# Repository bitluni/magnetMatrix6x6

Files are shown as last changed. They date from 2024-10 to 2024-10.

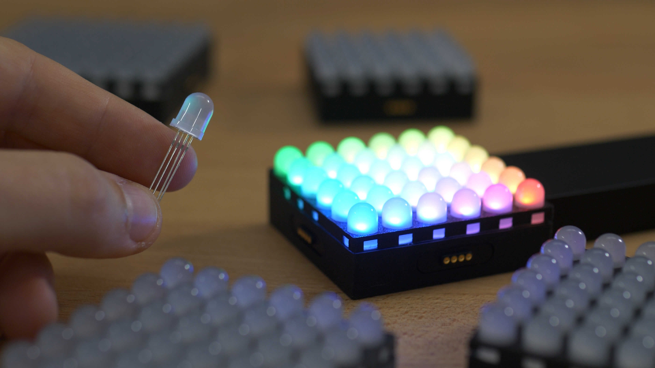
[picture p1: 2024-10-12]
cover.jpg

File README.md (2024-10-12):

# project video 
https://youtu.be/L2J_eNgjxio

# prerquisites 
Ardino IDE https://www.arduino.cc/en/software

ATTiny library https://github.com/SpenceKonde/megaTinyCore

UPDI progammer https://github.com/ElTangas/jtag2updi

# Parts (affiliate)
ATTiny1604

Magnet Connectors https://aliexpress.bitluni.net/magnetConnectors

WS2812D 5 & 8mm https://aliexpress.bitluni.net/ws2812d

# Support
https://paypal.me/bitluni

https://github.com/sponsors/bitluni

https://patreon.com/bitluni

have fun & thx for the support

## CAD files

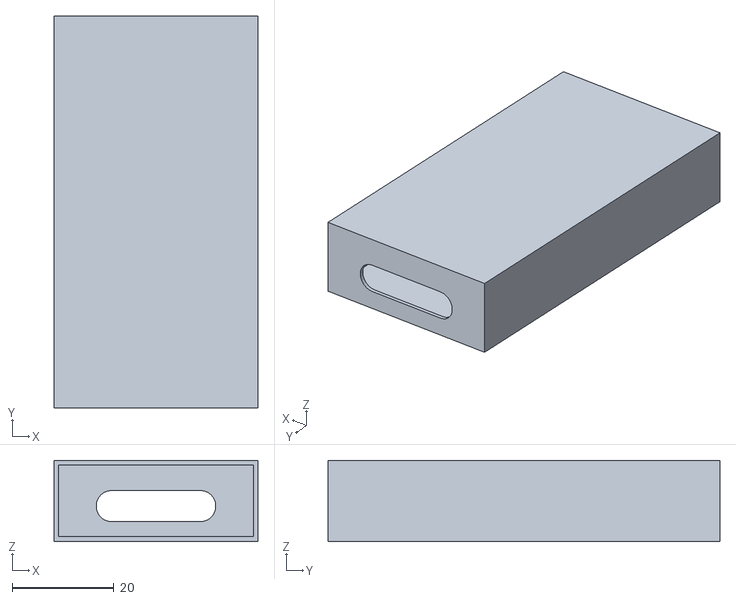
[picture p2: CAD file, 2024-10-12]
Models/battcase.stl
40.0 x 77.0 x 16.0

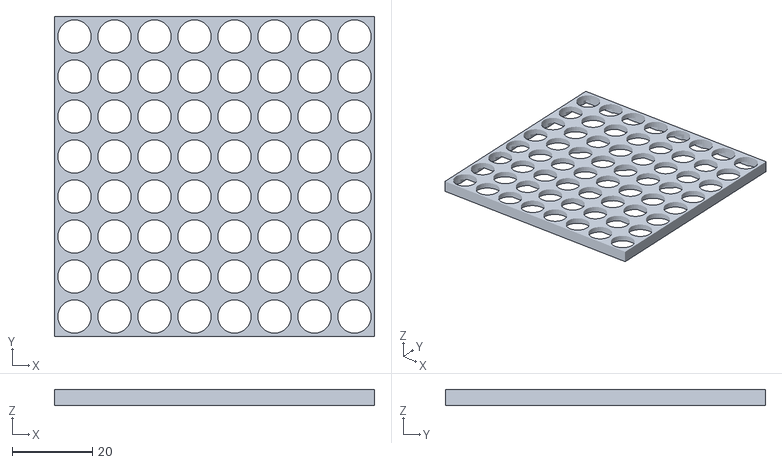
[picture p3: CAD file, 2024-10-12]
Models/top1.stl
80.0 x 80.0 x 4.00

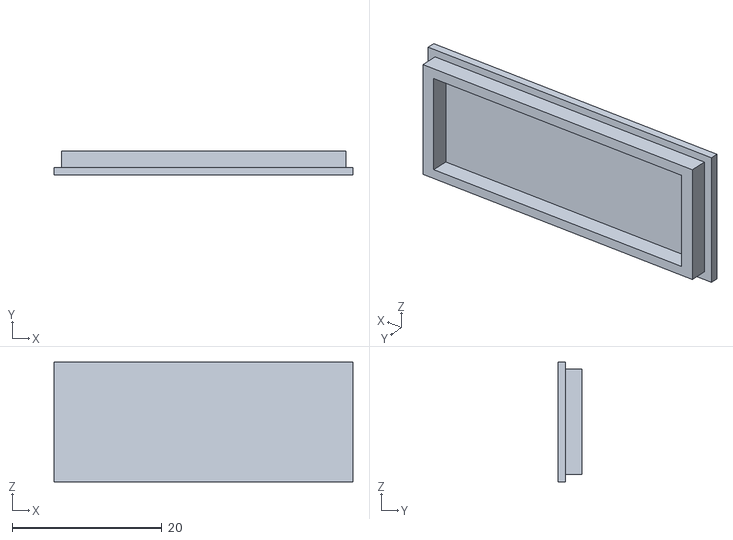
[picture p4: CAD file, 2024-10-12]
Models/battcap.stl
40.0 x 3.18 x 16.0

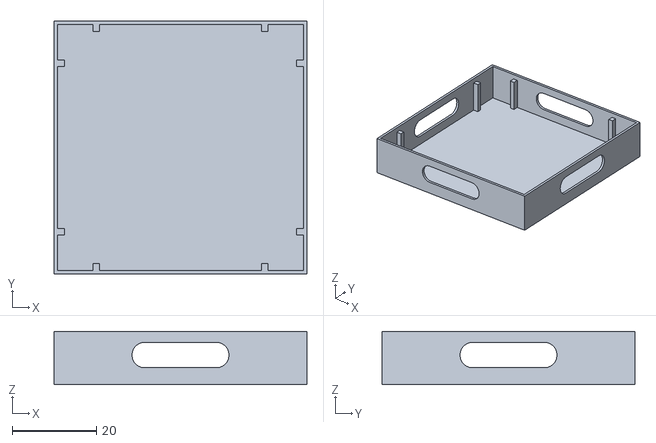
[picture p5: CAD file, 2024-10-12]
Models/bottom6x6.stl
60.0 x 60.0 x 12.6

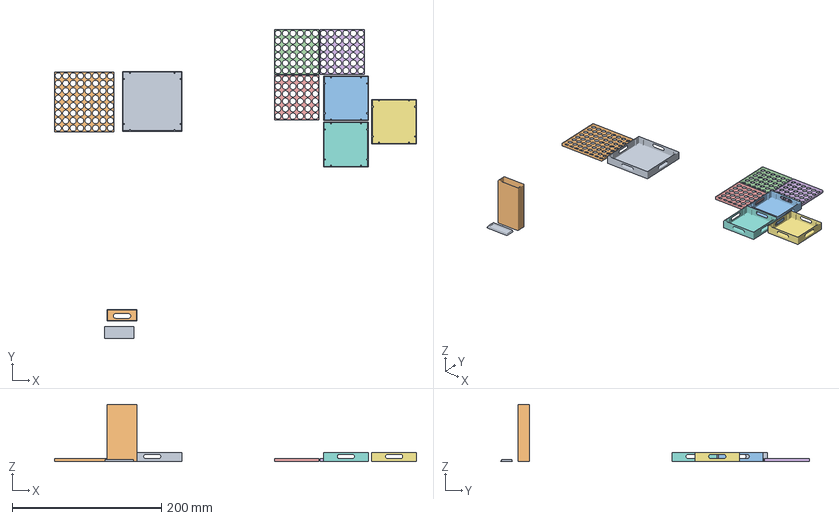
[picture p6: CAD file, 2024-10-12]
Models/parts.3mf
485.1 x 413.8 x 77.0 mm
bottom1.stl
top1.stl
bottom6x6.stl x 3
top6x6.stl x 3
battcap.stl
battcase.stl

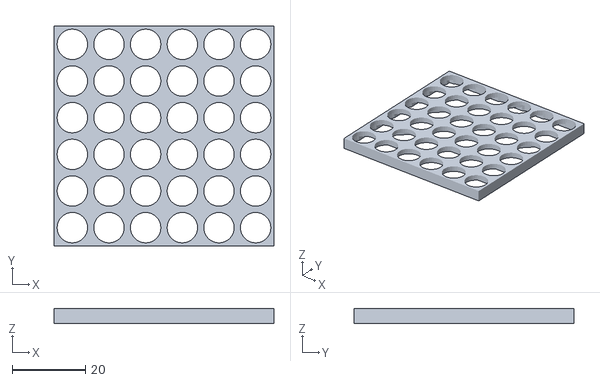
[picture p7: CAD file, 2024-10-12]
Models/top6x6.stl
60.0 x 60.0 x 4.00

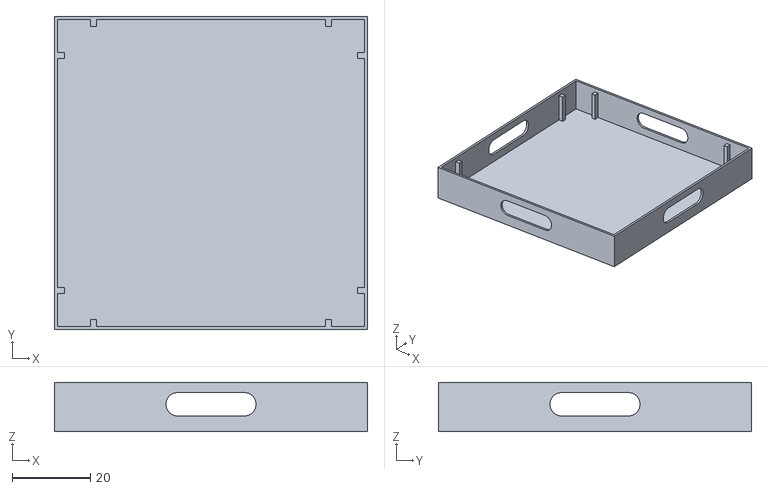
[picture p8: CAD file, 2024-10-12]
Models/bottom1.stl
80.0 x 80.0 x 12.6

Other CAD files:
Models/8x8.blend

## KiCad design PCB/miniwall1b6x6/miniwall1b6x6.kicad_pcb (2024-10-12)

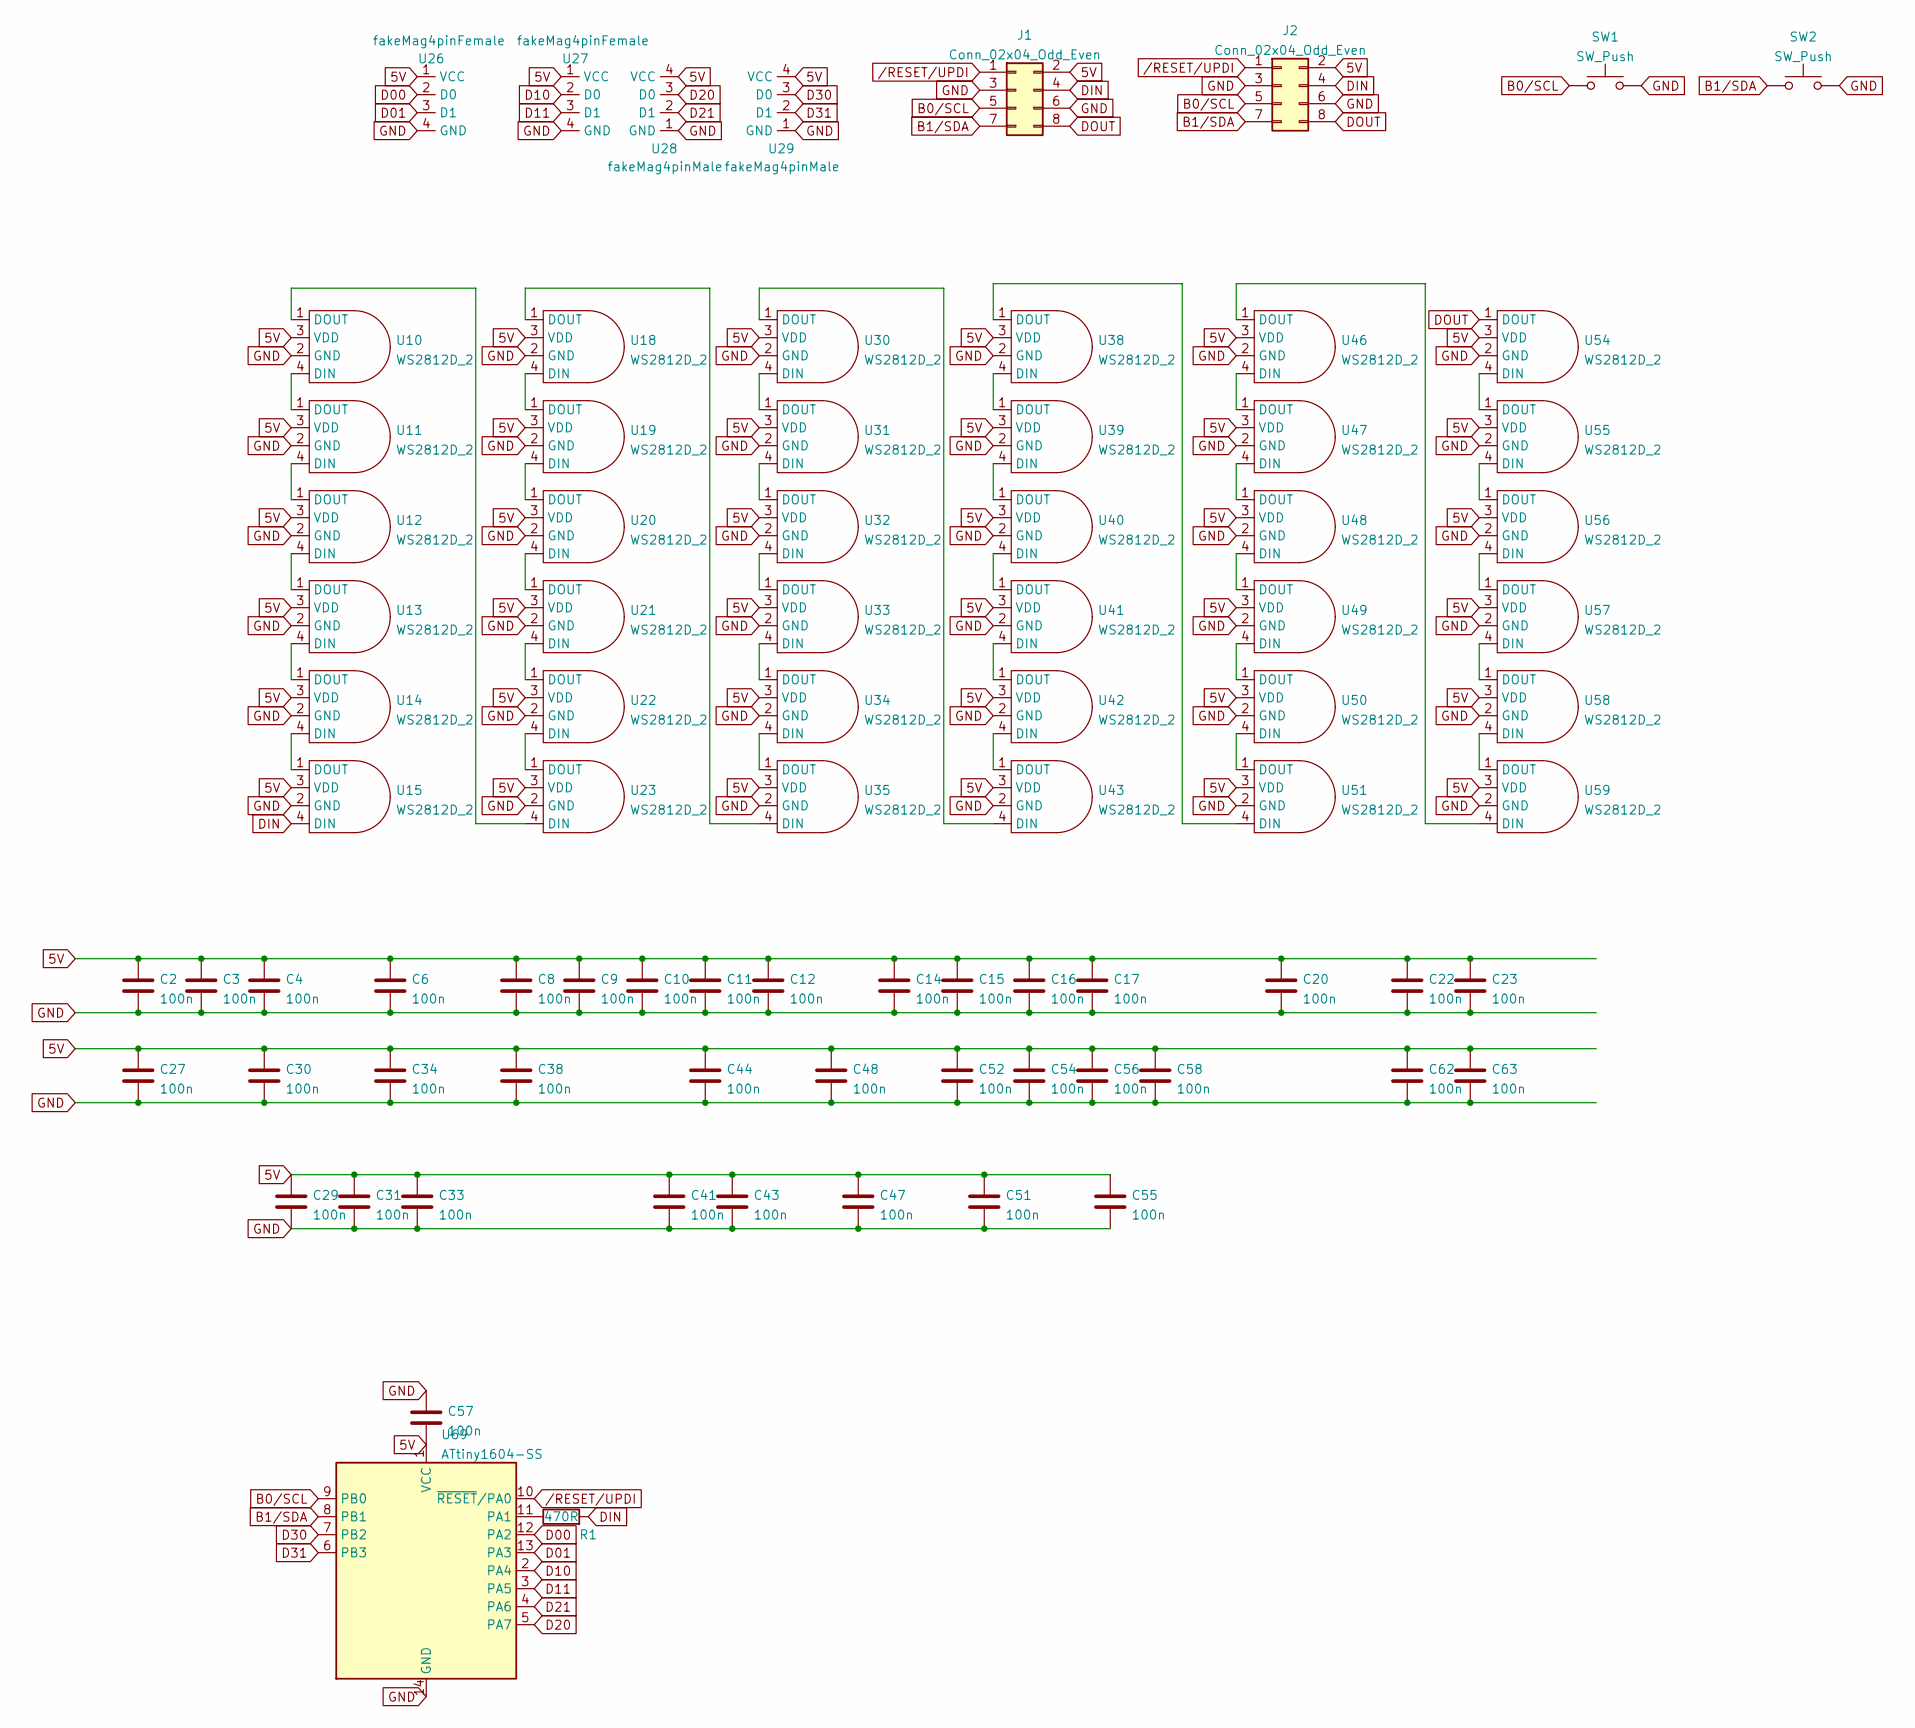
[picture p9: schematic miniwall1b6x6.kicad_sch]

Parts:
C2, C3, C4, C6, C8, C9, C10, C11, C12, C14, C15, C16, C17, C20, C22, C23, C27, C29, C30, C31, C33, C34, C38, C41, C43, C44, C47, C48, C51, C52, C54, C55, C56, C57, C58, C62, C63: 100n; C_0603_1608Metric
J1, J2: Conn_02x04_Odd_Even; PinHeader_2x04_P2.54mm_Vertical_SMD; MPN 54202-S08-04LF
R1: 470R; R_0603_1608Metric
SW1, SW2: SW_Push; SMD_ButtonC354946; MPN TSA343G00-250J2
U10, U11, U12, U13, U14, U15, U18, U19, U20, U21, U22, U23, U30, U31, U32, U33, U34, U35, U38, U39, U40, U41, U42, U43, U46, U47, U48, U49, U50, U51, U54, U55, U56, U57, U58, U59: WS2812D_2; WS2812DwideC
U26, U27: fakeMag4pinFemale; fakemag4pin90degFemale; MPN MG0422F-RA
U28, U29: fakeMag4pinMale; fakemag4pin90degMale; MPN MG0422F-RA
U69: ATtiny1604-SS; SOIC-14_3.9x8.7mm_P1.27mm

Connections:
5V: C2.1, C3.1, C4.1, C6.1, C8.1, C9.1, C10.1, C11.1, C12.1, C14.1, C15.1, C16.1, C17.1, C20.1, C22.1, C23.1, C27.1, C29.1, C30.1, C31.1, C33.1, C34.1, C38.1, C41.1, C43.1, C44.1, C47.1, C48.1, C51.1, C52.1, C54.1, C55.1, C56.1, C57.2, C58.1, C62.1, C63.1, J1.2, J2.2, U10.3 (VDD), U11.3 (VDD), U12.3 (VDD), U13.3 (VDD), U14.3 (VDD), U15.3 (VDD), U18.3 (VDD), U19.3 (VDD), U20.3 (VDD), U21.3 (VDD), U22.3 (VDD), U23.3 (VDD), U26.1 (VCC), U27.1 (VCC), U28.4 (VCC), U29.4 (VCC), U30.3 (VDD), U31.3 (VDD), U32.3 (VDD), U33.3 (VDD), U34.3 (VDD), U35.3 (VDD), U38.3 (VDD), U39.3 (VDD), U40.3 (VDD), U41.3 (VDD), U42.3 (VDD), U43.3 (VDD), U46.3 (VDD), U47.3 (VDD), U48.3 (VDD), U49.3 (VDD), U50.3 (VDD), U51.3 (VDD), U54.3 (VDD), U55.3 (VDD), U56.3 (VDD), U57.3 (VDD), U58.3 (VDD), U59.3 (VDD), U69.1 (VCC)
B0/SCL: J1.5, J2.5, SW1.1, U69.9 (PB0)
B1/SDA: J1.7, J2.7, SW2.1, U69.8 (PB1)
D00: U26.2 (D0), U69.12 (PA2)
D01: U26.3 (D1), U69.13 (PA3)
D10: U27.2 (D0), U69.2 (PA4)
D11: U27.3 (D1), U69.3 (PA5)
D20: U28.3 (D0), U69.5 (PA7)
D21: U28.2 (D1), U69.4 (PA6)
D30: U29.3 (D0), U69.7 (PB2)
D31: U29.2 (D1), U69.6 (PB3)
DIN: J1.4, J2.4, R1.2, U15.4 (DIN)
DOUT: J1.8, J2.8, U54.1 (DOUT)
GND: C2.2, C3.2, C4.2, C6.2, C8.2, C9.2, C10.2, C11.2, C12.2, C14.2, C15.2, C16.2, C17.2, C20.2, C22.2, C23.2, C27.2, C29.2, C30.2, C31.2, C33.2, C34.2, C38.2, C41.2, C43.2, C44.2, C47.2, C48.2, C51.2, C52.2, C54.2, C55.2, C56.2, C57.1, C58.2, C62.2, C63.2, J1.3, J1.6, J2.3, J2.6, SW1.2, SW2.2, U10.2 (GND), U11.2 (GND), U12.2 (GND), U13.2 (GND), U14.2 (GND), U15.2 (GND), U18.2 (GND), U19.2 (GND), U20.2 (GND), U21.2 (GND), U22.2 (GND), U23.2 (GND), U26.4 (GND), U27.4 (GND), U28.1 (GND), U29.1 (GND), U30.2 (GND), U31.2 (GND), U32.2 (GND), U33.2 (GND), U34.2 (GND), U35.2 (GND), U38.2 (GND), U39.2 (GND), U40.2 (GND), U41.2 (GND), U42.2 (GND), U43.2 (GND), U46.2 (GND), U47.2 (GND), U48.2 (GND), U49.2 (GND), U50.2 (GND), U51.2 (GND), U54.2 (GND), U55.2 (GND), U56.2 (GND), U57.2 (GND), U58.2 (GND), U59.2 (GND), U69.14 (GND)
unnamed: U10.4 (DIN), U11.1 (DOUT)
unnamed: U10.1 (DOUT), U23.4 (DIN)
unnamed: U11.4 (DIN), U12.1 (DOUT)
unnamed: U12.4 (DIN), U13.1 (DOUT)
unnamed: U13.4 (DIN), U14.1 (DOUT)
unnamed: U14.4 (DIN), U15.1 (DOUT)
unnamed: U18.4 (DIN), U19.1 (DOUT)
unnamed: U18.1 (DOUT), U35.4 (DIN)
unnamed: U19.4 (DIN), U20.1 (DOUT)
unnamed: U20.4 (DIN), U21.1 (DOUT)
unnamed: U21.4 (DIN), U22.1 (DOUT)
unnamed: U22.4 (DIN), U23.1 (DOUT)
unnamed: U30.4 (DIN), U31.1 (DOUT)
unnamed: U30.1 (DOUT), U43.4 (DIN)
unnamed: U31.4 (DIN), U32.1 (DOUT)
unnamed: U32.4 (DIN), U33.1 (DOUT)
unnamed: U33.4 (DIN), U34.1 (DOUT)
unnamed: U34.4 (DIN), U35.1 (DOUT)
unnamed: U38.4 (DIN), U39.1 (DOUT)
unnamed: U38.1 (DOUT), U51.4 (DIN)
unnamed: U39.4 (DIN), U40.1 (DOUT)
unnamed: U40.4 (DIN), U41.1 (DOUT)
unnamed: U41.4 (DIN), U42.1 (DOUT)
unnamed: U42.4 (DIN), U43.1 (DOUT)
unnamed: U46.4 (DIN), U47.1 (DOUT)
unnamed: U46.1 (DOUT), U59.4 (DIN)
unnamed: U47.4 (DIN), U48.1 (DOUT)
unnamed: U48.4 (DIN), U49.1 (DOUT)
unnamed: U49.4 (DIN), U50.1 (DOUT)
unnamed: U50.4 (DIN), U51.1 (DOUT)
unnamed: U54.4 (DIN), U55.1 (DOUT)
unnamed: U55.4 (DIN), U56.1 (DOUT)
unnamed: U56.4 (DIN), U57.1 (DOUT)
unnamed: U57.4 (DIN), U58.1 (DOUT)
unnamed: U58.4 (DIN), U59.1 (DOUT)
unnamed: R1.1, U69.11 (PA1)
/RESET/UPDI: J1.1, J2.1, U69.10 (~RESET/PA0)

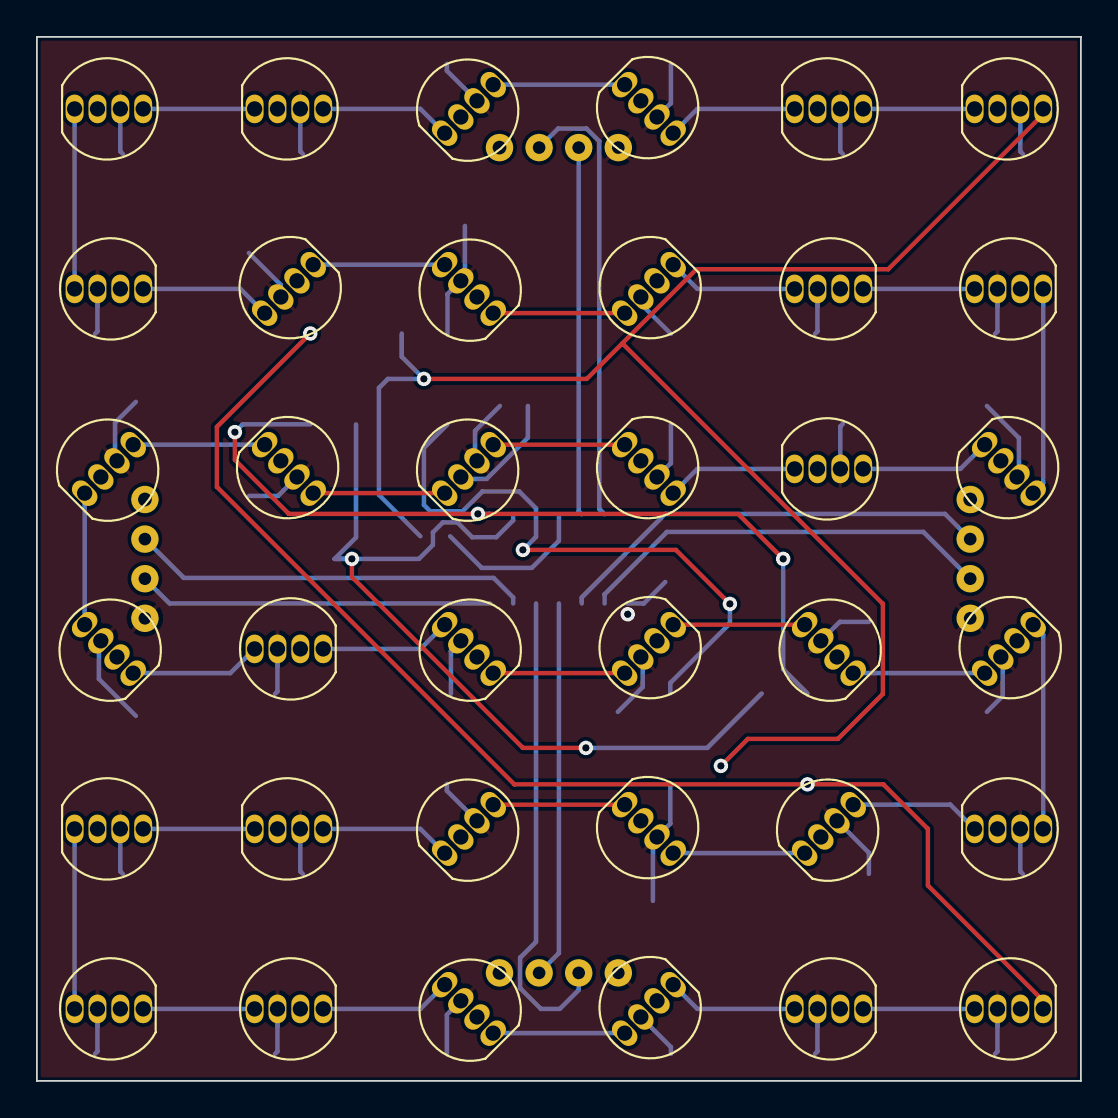
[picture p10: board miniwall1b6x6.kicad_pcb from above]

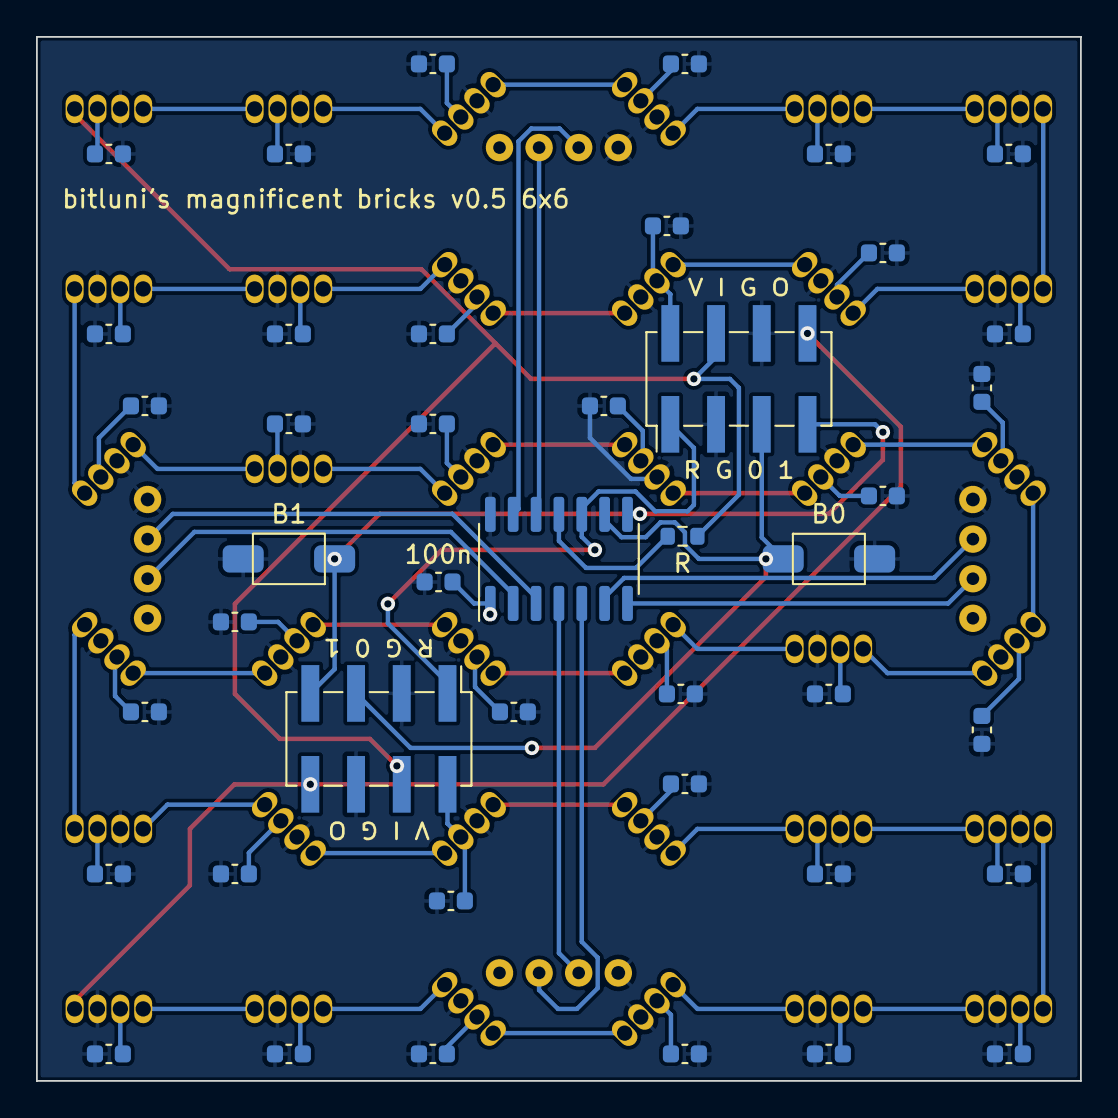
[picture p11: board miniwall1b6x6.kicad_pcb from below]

Board: 2 copper layers, 58.0 x 58.0 mm, 83 parts (43 on the bottom side), 51 nets.

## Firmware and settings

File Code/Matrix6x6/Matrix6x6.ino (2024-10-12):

#include <tinyNeoPixel_Static.h>

const int ledPin = PIN_PA1;
const unsigned char xres = 6;
const unsigned char yres = 6;
const int ledBufferSize = xres * yres * 3;
unsigned char ledBuffer[ledBufferSize];

const int pins[4][2] = {{PIN_PA2, PIN_PA3}, {PIN_PA4, PIN_PA5}, {PIN_PA6, PIN_PA7}, {PIN_PB2, PIN_PB3}};


tinyNeoPixel leds = tinyNeoPixel(xres * yres, ledPin, NEO_GRB, ledBuffer);

int dimm = 4;

void fill(int i)
{
  for(int y = 0; y < yres; y++)
    for(int x = 0; x < xres; x++)
    {
      int cx = y & 1 ? xres - 1 - x : x;
      ledBuffer[(x + y * xres) * 3 + 0] = (((cx + i)%xres) * 256 / xres) >> dimm;  
      ledBuffer[(x + y * xres) * 3 + 1] = (((y + i)%yres) * 256 / yres) >> dimm;  
      ledBuffer[(x + y * xres) * 3 + 2] = ((xres - max(cx,y) - 1) * 256 / xres) >> dimm;
    }
}
void clear()
{
  for(int i = 0; i < xres * yres * 3; i++)
      ledBuffer[i] = 0;
}

int addr(int x, int y)
{
  if(y & 1)
    return (y * xres + xres - 1 - x) * 3;
  else
    return (y * xres + x) * 3;
}

void showSides(int i, int sides)
{
  clear();
  for(int x = 0; x < xres; x++)
  {
    if((sides & 1) == 0)
    if(((3-x) & 3) == (i & 3))
    {
      ledBuffer[(x + 0) * 3 + 0] = 255 >> dimm;
      ledBuffer[(x + 0) * 3 + 1] = 255 >> dimm;
      ledBuffer[(x + 0) * 3 + 2] = 255 >> dimm;
    }
    if((sides & 4) == 0)
    if(((3-x) & 3) == (i & 3))
    {
      ledBuffer[(x + (yres - 1) * xres) * 3 + 0] = 255 >> dimm;
      ledBuffer[(x + (yres - 1) * xres) * 3 + 1] = 255 >> dimm;
      ledBuffer[(x + (yres - 1) * xres) * 3 + 2] = 255 >> dimm;
    }
  }
  for(int y = 0; y < yres; y++)
  {
    if((sides & 2) == 0)
    if((y & 3) == (i & 3))
    {
      ledBuffer[addr(0, y) + 0] = 255 >> dimm;
      ledBuffer[addr(0, y) + 1] = 255 >> dimm;
      ledBuffer[addr(0, y) + 2] = 255 >> dimm;
    }
    if((sides & 8) == 0)
    if(((3 - y) & 3) == (i & 3))
    {
      ledBuffer[addr(xres - 1, y) + 0] = 255 >> dimm;
      ledBuffer[addr(xres - 1, y) + 1] = 255 >> dimm;
      ledBuffer[addr(xres - 1, y) + 2] = 255 >> dimm;
    }
  }
}

void setup() 
{
  //led
  pinMode(ledPin, OUTPUT);
  //magnet connectors
  pinMode(pins[0][0], INPUT_PULLUP);
  pinMode(pins[0][1], OUTPUT); digitalWrite(pins[0][1], 0);
  pinMode(pins[1][0], INPUT_PULLUP);
  pinMode(pins[1][1], OUTPUT); digitalWrite(pins[1][1], 0);
  pinMode(pins[2][0], INPUT_PULLUP);
  pinMode(pins[2][1], OUTPUT); digitalWrite(pins[2][1], 0);
  pinMode(pins[3][1], INPUT_PULLUP);
  pinMode(pins[3][0], OUTPUT); digitalWrite(pins[3][0], 0);
  //buttons
  pinMode(PIN_PB0, INPUT_PULLUP);
  pinMode(PIN_PB1, INPUT_PULLUP);

  fill(0);
}

void loop() 
{
  static int i = 0;
  int sides = 
    (digitalRead(pins[0][0]) ? 0 : 1) + 
    (digitalRead(pins[1][0]) ? 0 : 2) + 
    (digitalRead(pins[2][0]) ? 0 : 4) + 
    (digitalRead(pins[3][1]) ? 0 : 8);
  int buttons = 
    (digitalRead(PIN_PB0) ? 0 : 1) + 
    (digitalRead(PIN_PB1) ? 0 : 2);
  static int oldButtons = 0;
  if(oldButtons != 0 && buttons == 0)
    dimm = (dimm + 1) % 6;
  oldButtons = buttons;
  if(sides)
    showSides(i, sides);
  else
    fill(i);
  i++;
  leds.show();
  delay(50);
}
